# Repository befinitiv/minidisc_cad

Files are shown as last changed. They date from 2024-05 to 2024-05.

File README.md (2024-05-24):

# Minidisc

This repository contains the CAD files (PCB & mechanics) for the 8cm "minidisc" player project.

The PCB is designed using Kicad 8, the mechanics is designed using build123d.

## Buld123d environment installation

1. Install direnv
2. Go into the mech/ subfolder, so that the Python environment specified in .envrc file is loaded
3. Install packages: `pip install -r requirements.txt`
4. Start GUI: `jupyter lab`

# BOM
* Display: https://www.reichelt.de/grafik-oled-0-84-zoll-96x16-dot-weiss-ziff-ea-w096016-xblw-p364744.html?&nbc=1
* Bluray drive: https://www.reichelt.de/verbatim-externer-slimline-blu-ray-brenner-verbatim-43889-p264365.html?search=bluray
* Battery: https://www.reichelt.de/mp3-player-akku-fuer-apple-ipod-li-po-1043-mah-akku-30933-p224503.html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
* All other parts are within the Kicad PCB BOM

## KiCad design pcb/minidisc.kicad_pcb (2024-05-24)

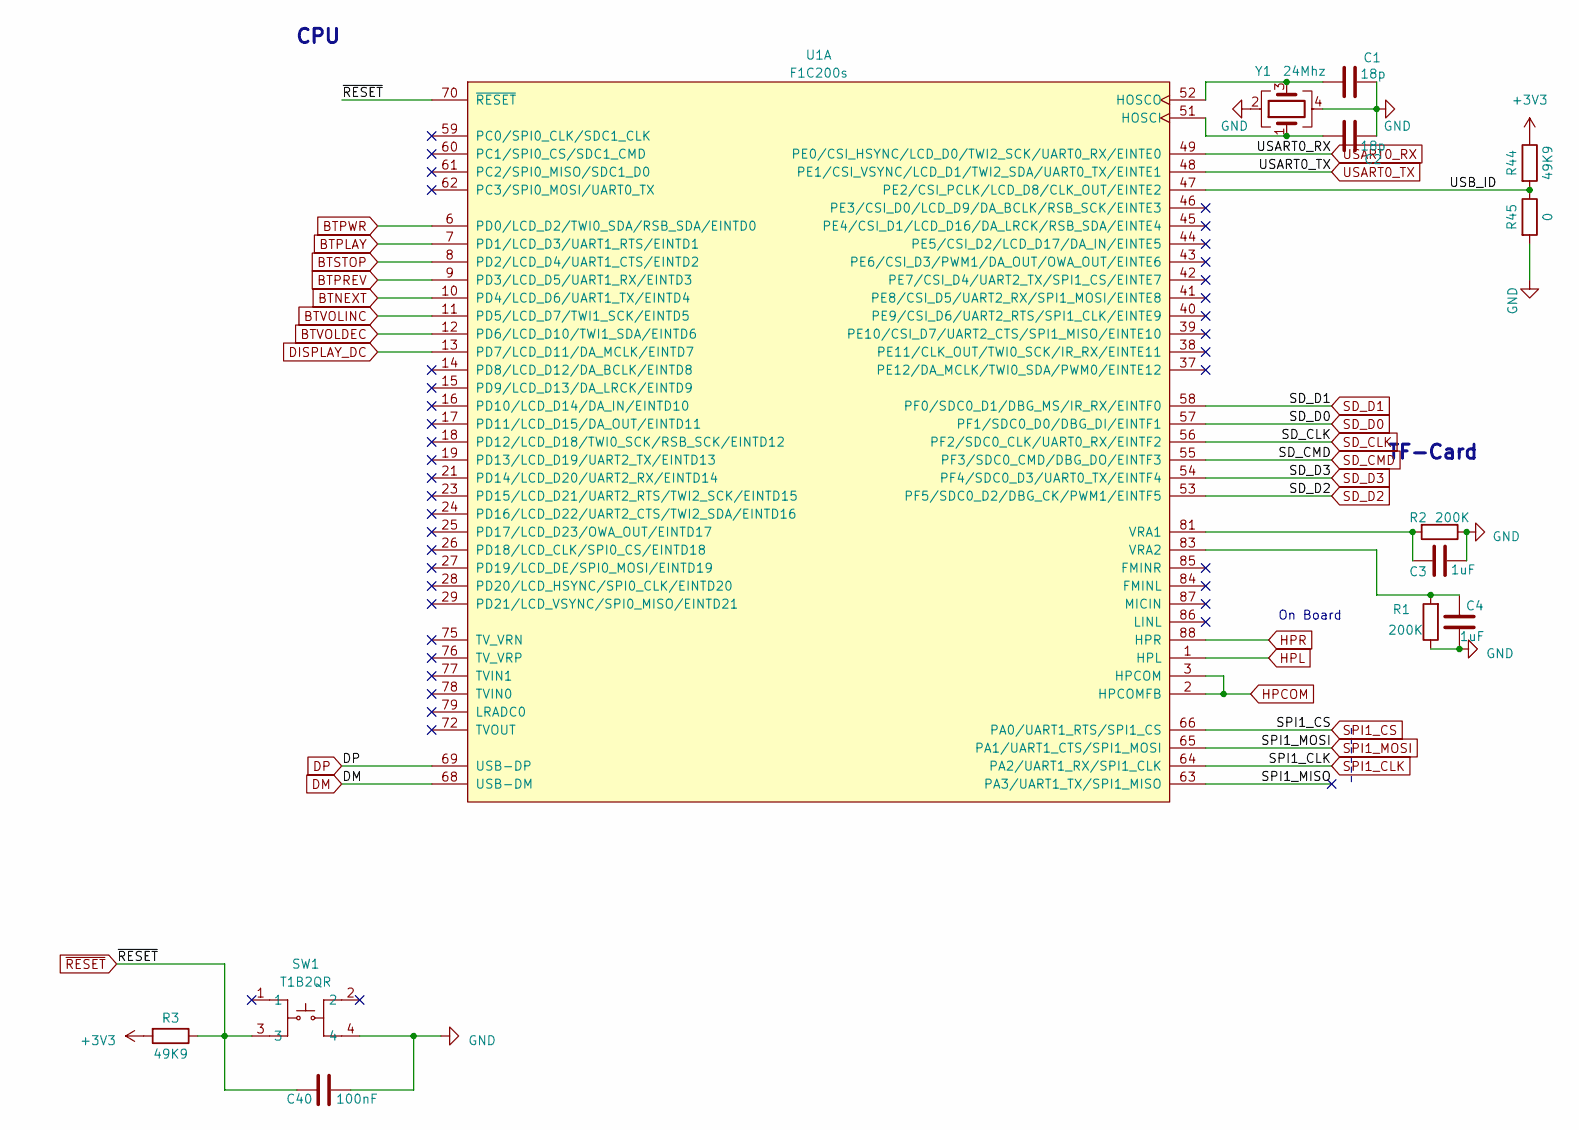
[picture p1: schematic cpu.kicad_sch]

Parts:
C1, C2: 18p; C_0402_1005Metric
C3, C4: 1uF; C_0402_1005Metric
C40: 100nF; C_0402_1005Metric_Pad0.74x0.62mm_HandSolder
R1, R2: 200K; R_0402_1005Metric_Pad0.72x0.64mm_HandSolder
R3, R44: 49K9; R_0402_1005Metric_Pad0.72x0.64mm_HandSolder
R45: 0; R_0402_1005Metric_Pad0.72x0.64mm_HandSolder
SW1: T1B2QR; KEY-SMD_4P-L2.6-W1.6-P0.80-LS3.0-1; LCSC Part C495946
U1: F1C200s; QFN-88_L10.0-W10.0-P0.40-BL-EP6.75
Y1: 24Mhz; Crystal_SMD_3225-4Pin_3.2x2.5mm; LCSC C5160135

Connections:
+3V3: R3.2, R44.1; also elsewhere on the board
/cpu/SPI1_MISO: U1.63 (PA3/UART1_TX/SPI1_MISO)
/cpu/USB_ID: R44.2, R45.1, U1.47 (PE2/CSI_PCLK/LCD_D8/CLK_OUT/EINTE2)
BTNEXT: U1.10 (PD4/LCD_D6/UART1_TX/EINTD4); also elsewhere on the board
BTPLAY: U1.7 (PD1/LCD_D3/UART1_RTS/EINTD1); also elsewhere on the board
BTPREV: U1.9 (PD3/LCD_D5/UART1_RX/EINTD3); also elsewhere on the board
BTPWR: U1.6 (PD0/LCD_D2/TWI0_SDA/RSB_SDA/EINTD0); also elsewhere on the board
BTSTOP: U1.8 (PD2/LCD_D4/UART1_CTS/EINTD2); also elsewhere on the board
BTVOLDEC: U1.12 (PD6/LCD_D10/TWI1_SDA/EINTD6); also elsewhere on the board
BTVOLINC: U1.11 (PD5/LCD_D7/TWI1_SCK/EINTD5); also elsewhere on the board
DISPLAY_DC: U1.13 (PD7/LCD_D11/DA_MCLK/EINTD7); also elsewhere on the board
DM: U1.68 (USB-DM); also elsewhere on the board
DP: U1.69 (USB-DP); also elsewhere on the board
GND: C1.1, C2.1, C3.1, C4.1, C40.2, R1.1, R2.1, R45.2, SW1.4, Y1.2, Y1.4; also elsewhere on the board
HPCOM: U1.2 (HPCOMFB), U1.3 (HPCOM); also elsewhere on the board
HPL: U1.1 (HPL); also elsewhere on the board
HPR: U1.88 (HPR); also elsewhere on the board
unnamed: C2.2, U1.51 (HOSCI), Y1.1
unnamed: C1.2, U1.52 (HOSCO), Y1.3
unnamed: C3.2, R2.2, U1.81 (VRA1)
unnamed: C4.2, R1.2, U1.83 (VRA2)
SD_D0: U1.57 (PF1/SDC0_D0/DBG_DI/EINTF1); also elsewhere on the board
SD_D1: U1.58 (PF0/SDC0_D1/DBG_MS/IR_RX/EINTF0); also elsewhere on the board
SD_D2: U1.53 (PF5/SDC0_D2/DBG_CK/PWM1/EINTF5); also elsewhere on the board
SD_D3: U1.54 (PF4/SDC0_D3/UART0_TX/EINTF4); also elsewhere on the board
SPI1_CLK: U1.64 (PA2/UART1_RX/SPI1_CLK); also elsewhere on the board
SPI1_CS: U1.66 (PA0/UART1_RTS/SPI1_CS); also elsewhere on the board
SPI1_MOSI: U1.65 (PA1/UART1_CTS/SPI1_MOSI); also elsewhere on the board
USART0_RX: U1.49 (PE0/CSI_HSYNC/LCD_D0/TWI2_SCK/UART0_RX/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); also elsewhere on the board
USART0_TX: U1.48 (PE1/CSI_VSYNC/LCD_D1/TWI2_SDA/UART0_TX/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); also elsewhere on the board
~RESET: C40.1, R3.1, SW1.3, U1.70 (~RESET); also elsewhere on the board

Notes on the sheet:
On Board
TF-Card
CPU

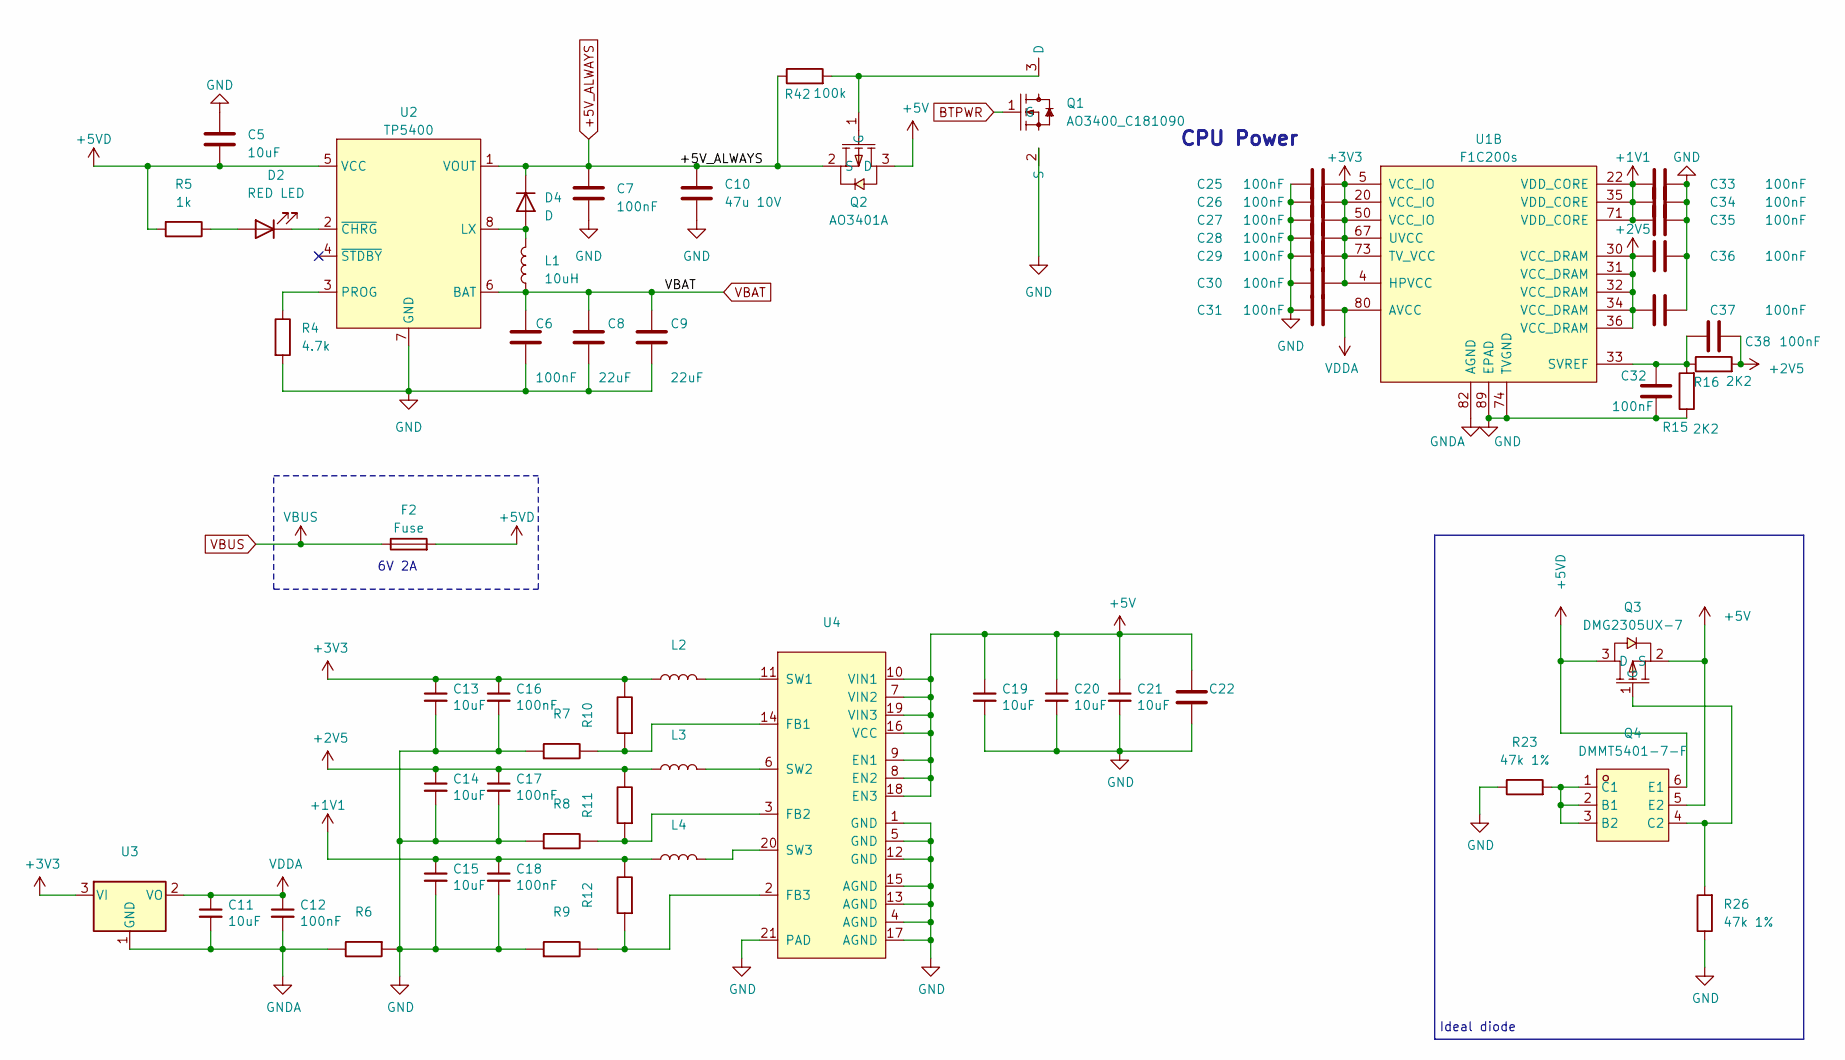
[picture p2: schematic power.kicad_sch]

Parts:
C5: 10uF; C_0603_1608Metric
C6: 100nF; C_0402_1005Metric
C7, C25, C26, C27, C28, C29, C30, C31, C32, C33, C34, C35, C36, C37, C38: 100nF; C_0402_1005Metric_Pad0.74x0.62mm_HandSolder
C8, C9: 22uF; C_0805_2012Metric
C10, C22: 47u 10V; C_1210_3225Metric
C11, C13, C14, C15, C19, C20, C21: 03.4004_C0603_10uF; C_0603_1608Metric
C12, C16, C17: 03.0009_C0402_100nF; C_0402_1005Metric
C18: 03.0009_C0402_100nF; R_0402_1005Metric
D2: RED LED; LED_0402_1005Metric
D4: D; D_SMA; LCSC C34897
F2: Fuse; Fuse_1206_3216Metric; LCSC C720076
L1: 10uH; IND-SMD_L4.0-W4.0
L2, L3, L4: 06.0102_L2520_2.2uH; L_1008_2520Metric; LCSC C315721
Q1: AO3400_C181090; SOT-23-3_L2.9-W1.3-P1.90-LS2.4-BR; LCSC Part C181090
Q2: AO3401A; SOT-23_L2.9-W1.3-P1.90-LS2.4-BR; LCSC Part C15127
Q3: DMG2305UX-7; SOT-23-3_L2.9-W1.3-P1.90-LS2.4-BR; LCSC Part C150470
Q4: DMMT5401-7-F; SOT-23-6_L2.9-W1.6-P0.95-LS2.8-BR; LCSC Part C154733
R4: 4.7k; R_0402_1005Metric
R5: 1k; R_0402_1005Metric
R6: 0; R_0402_1005Metric
R7, R8, R9, R12: 150K 1%; R_0402_1005Metric; LCSC C3015896
R10: 680K 1%; R_0402_1005Metric; LCSC C2909377
R11: 470K 1%; R_0402_1005Metric
R15, R16: 2K2; R_0402_1005Metric_Pad0.72x0.64mm_HandSolder
R23, R26: 47k 1%; R_0402_1005Metric
R42: 100k; R_0402_1005Metric_Pad0.72x0.64mm_HandSolder
U1: F1C200s; QFN-88_L10.0-W10.0-P0.40-BL-EP6.75
U2: TP5400; ESOP-8_L4.9-W3.9-P1.27-LS6.0-BL-EP
U3: 09.0103_XC6206; SOT-23; LCSC C347375
U4: 09.0102_EA3036; WQFN-20-1EP_3x3mm_P0.4mm_EP1.7x1.7mm_ThermalVias; LCSC C570857

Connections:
+1V1: C15.1, C18.1, C33.1, C34.1, C35.1, L4.1, R12.2, U1.22 (VDD_CORE), U1.35 (VDD_CORE), U1.71 (VDD_CORE)
+2V5: C14.1, C17.1, C36.1, C37.1, C38.1, L3.1, R11.2, R16.2, U1.30 (VCC_DRAM), U1.31 (VCC_DRAM), U1.32 (VCC_DRAM), U1.34 (VCC_DRAM), U1.36 (VCC_DRAM)
+3V3: C13.1, C16.1, C25.2, C26.2, C27.2, C28.2, C29.2, C30.2, L2.1, R10.2, U1.4 (HPVCC), U1.5 (VCC_IO), U1.20 (VCC_IO), U1.50 (VCC_IO), U1.67 (UVCC), U1.73 (TV_VCC), U3.3 (VI); also elsewhere on the board
+5V: C19.1, C20.1, C21.1, C22.1, Q2.3 (D), Q3.2 (S), Q4.5 (E2), U4.7 (VIN2), U4.8 (EN2), U4.9 (EN1), U4.10 (VIN1), U4.16 (VCC), U4.18 (EN3), U4.19 (VIN3); also elsewhere on the board
+5VD: C5.2, F2.2, Q3.3 (D), Q4.6 (E1), R5.2, U2.5 (VCC); also elsewhere on the board
+5V_ALWAYS: C7.1, C10.1, D4.1 (K), Q2.2 (S), R42.1, U2.1 (VOUT); also elsewhere on the board
BTPWR: Q1.1 (G); also elsewhere on the board
GND: C5.1, C6.2, C7.2, C8.2, C9.2, C10.2, C13.2, C14.2, C15.2, C16.2, C17.2, C18.2, C19.2, C20.2, C21.2, C22.2, C25.1, C26.1, C27.1, C28.1, C29.1, C30.1, C31.1, C32.1, C33.2, C34.2, C35.2, C36.2, C37.2, Q1.2 (S), R4.2, R6.1, R7.1, R8.1, R9.1, R15.1, R23.1, R26.1, U1.74 (TVGND), U1.89 (EPAD), U2.7 (GND), U4.1 (GND), U4.4 (AGND), U4.5 (GND), U4.12 (GND), U4.13 (AGND), U4.15 (AGND), U4.17 (AGND), U4.21 (PAD); also elsewhere on the board
GNDA: C11.2, C12.2, R6.2, U1.82 (AGND), U3.1 (GND)
unnamed: D2.2 (A), R5.1
unnamed: D2.1 (K), U2.2 (~CHRG)
unnamed: D4.2 (A), L1.1, U2.8 (LX)
unnamed: Q1.3 (D), Q2.1 (G), R42.2
unnamed: Q3.1 (G), Q4.4 (C2), R26.2
unnamed: Q4.1 (C1), Q4.2 (B1), Q4.3 (B2), R23.2
unnamed: C32.2, C38.2, R15.2, R16.1, U1.33 (SVREF)
unnamed: R4.1, U2.3 (PROG)
unnamed: R7.2, R10.1, U4.14 (FB1)
unnamed: R8.2, R11.1, U4.3 (FB2)
unnamed: R9.2, R12.1, U4.2 (FB3)
unnamed: L2.2, U4.11 (SW1)
unnamed: L3.2, U4.6 (SW2)
unnamed: L4.2, U4.20 (SW3)
VBAT: C6.1, C8.1, C9.1, L1.2, U2.6 (BAT); also elsewhere on the board
VBUS: F2.1; also elsewhere on the board
VDDA: C11.1, C12.1, C31.2, U1.80 (AVCC), U3.2 (VO)

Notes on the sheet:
6V 2A
CPU Power
Ideal diode

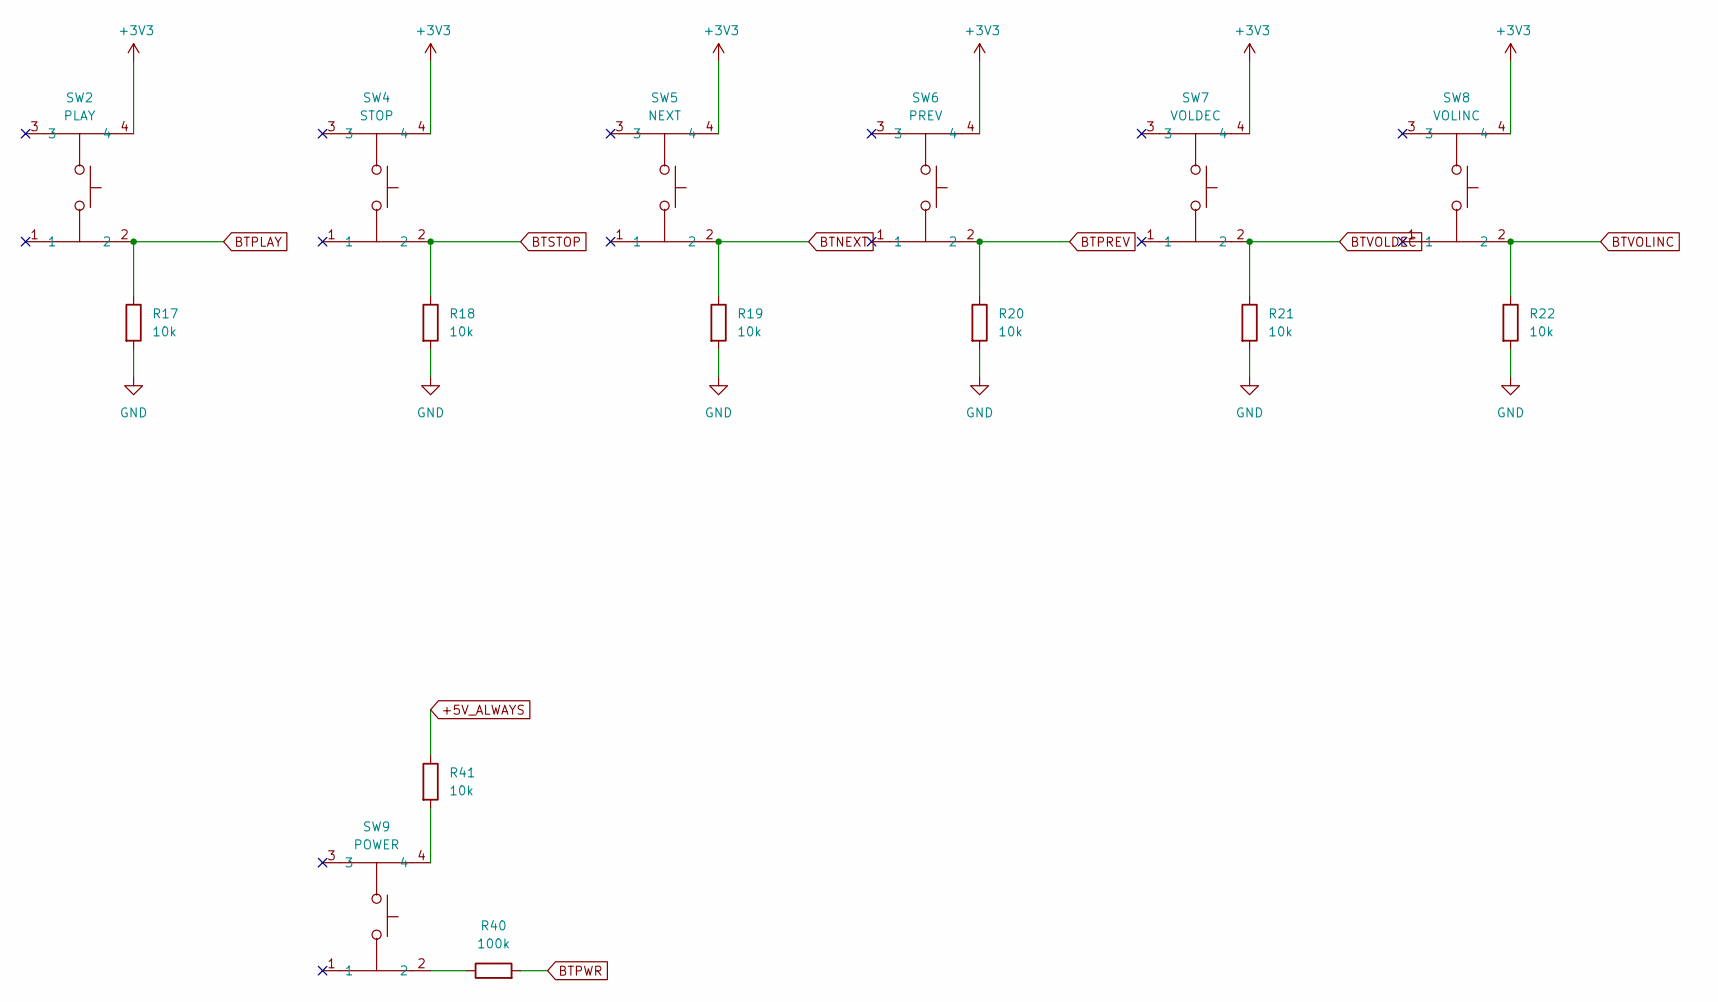
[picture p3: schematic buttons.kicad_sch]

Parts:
R17, R18, R19, R20, R21, R22, R41: 10k; R_0402_1005Metric
R40: 100k; R_0402_1005Metric
SW2: PLAY; SW-SMD_4P-L3.5-W2.9-P1.30-LS4.8; LCSC Part C130445
SW4: STOP; SW-SMD_4P-L3.5-W2.9-P1.30-LS4.8; LCSC Part C130445
SW5: NEXT; SW-SMD_4P-L3.5-W2.9-P1.30-LS4.8; LCSC Part C130445
SW6: PREV; SW-SMD_4P-L3.5-W2.9-P1.30-LS4.8; LCSC Part C130445
SW7: VOLDEC; SW-SMD_4P-L3.5-W2.9-P1.30-LS4.8; LCSC Part C130445
SW8: VOLINC; SW-SMD_4P-L3.5-W2.9-P1.30-LS4.8; LCSC Part C130445
SW9: POWER; SW-SMD_4P-L3.5-W2.9-P1.30-LS4.8; LCSC Part C130445

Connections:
+3V3: SW2.4, SW4.4, SW5.4, SW6.4, SW7.4, SW8.4; also elsewhere on the board
+5V_ALWAYS: R41.1; also elsewhere on the board
BTNEXT: R19.1, SW5.2; also elsewhere on the board
BTPLAY: R17.1, SW2.2; also elsewhere on the board
BTPREV: R20.1, SW6.2; also elsewhere on the board
BTPWR: R40.2; also elsewhere on the board
BTSTOP: R18.1, SW4.2; also elsewhere on the board
BTVOLDEC: R21.1, SW7.2; also elsewhere on the board
BTVOLINC: R22.1, SW8.2; also elsewhere on the board
GND: R17.2, R18.2, R19.2, R20.2, R21.2, R22.2; also elsewhere on the board
unnamed: R40.1, SW9.2
unnamed: R41.2, SW9.4

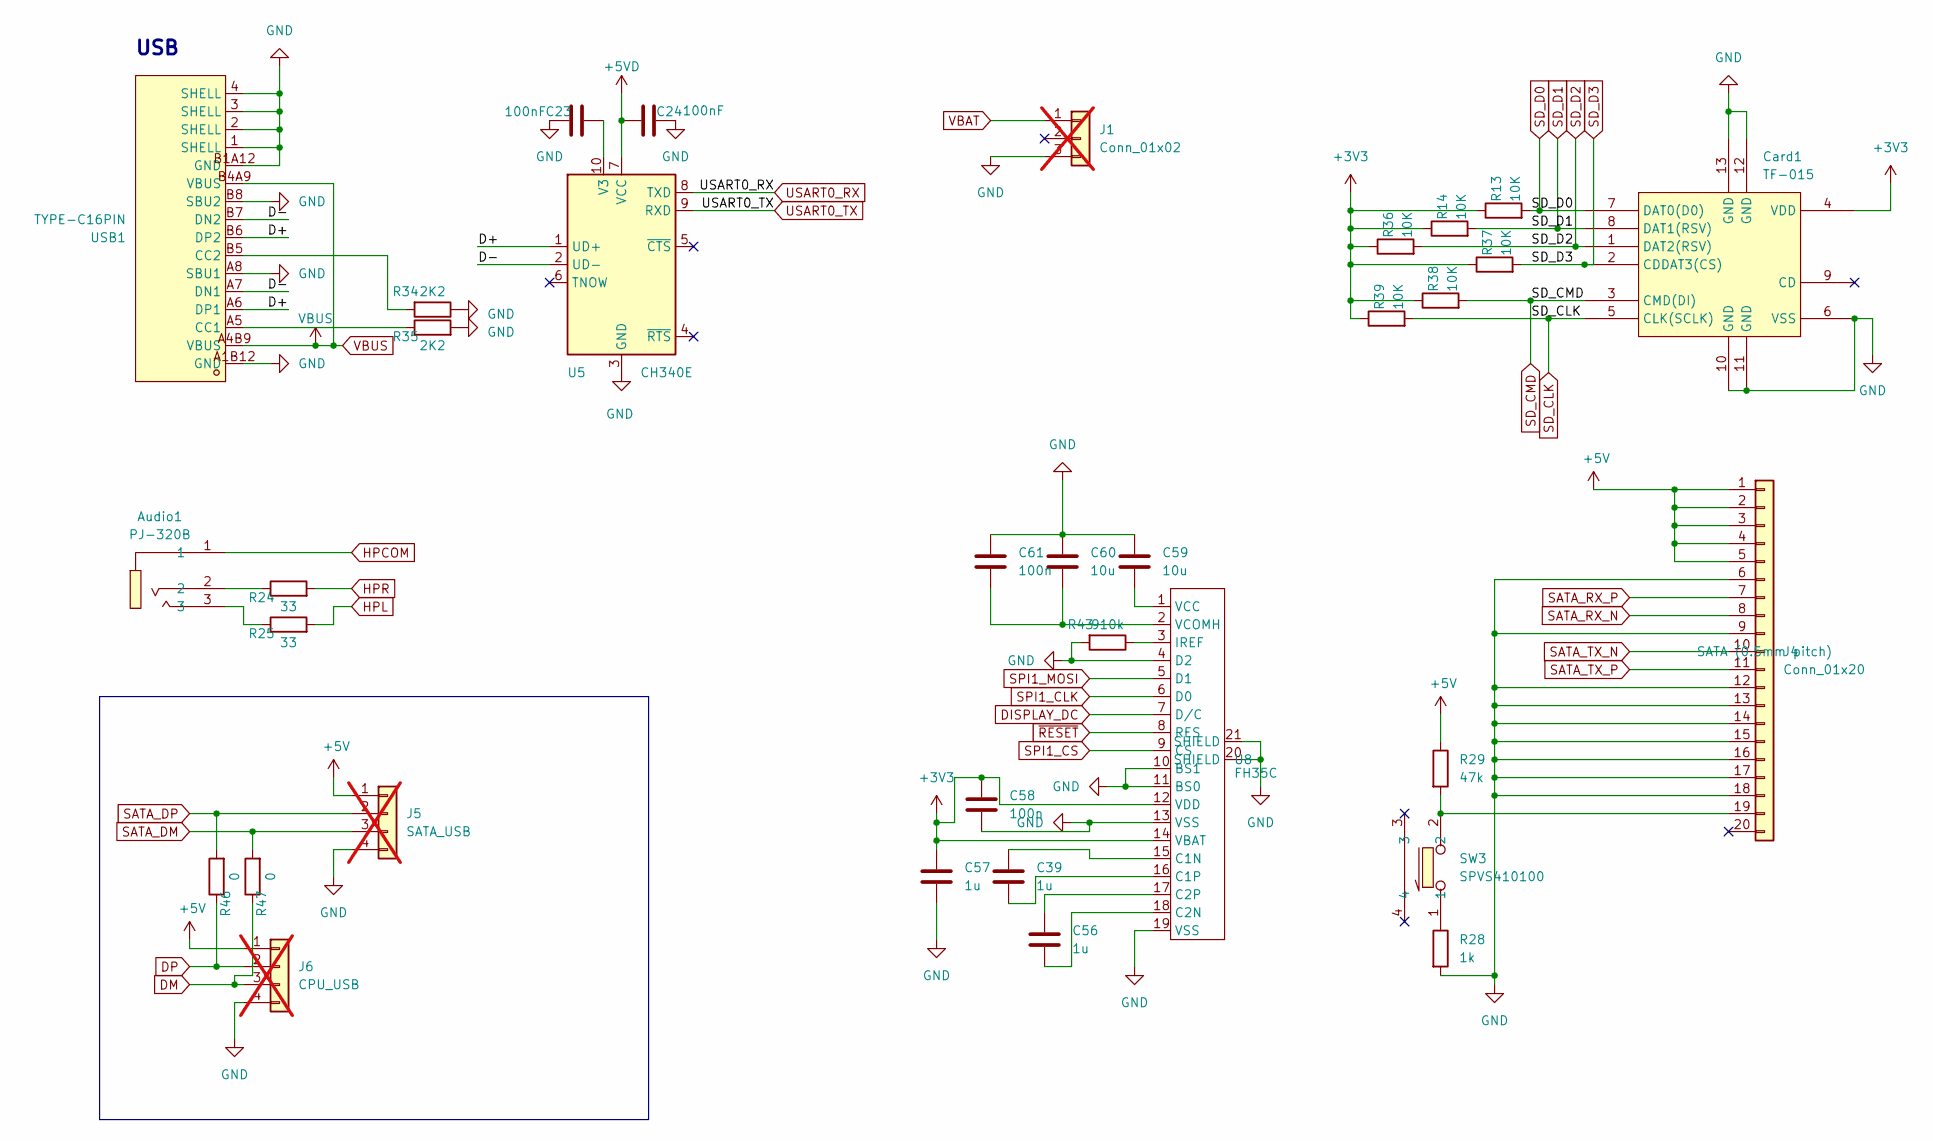
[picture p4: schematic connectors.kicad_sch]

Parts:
Audio1: PJ-320B; AUDIO-SMD_PJ-320B; LCSC Part C18594
C23, C24: 100nF; C_0402_1005Metric_Pad0.74x0.62mm_HandSolder
C39, C56, C57: 1u; C_0402_1005Metric
C58, C61: 100n; C_0402_1005Metric
C59, C60: 10u; C_0603_1608Metric
Card1: TF-015; TF-SMD_TF-015; LCSC Part C113206
J1: Conn_01x02; ipodbattery; not fitted
J4: Conn_01x20; Hirose_FH12-20S-0.5SH_1x20-1MP_P0.50mm_Horizontal; LCSC C596730
J5: SATA_USB; PinHeader_1x04_P1.00mm_Vertical; not fitted
J6: CPU_USB; PinHeader_1x04_P1.00mm_Vertical; not fitted
R13, R14, R36, R37, R38, R39: 10K; R_0402_1005Metric_Pad0.72x0.64mm_HandSolder
R24, R25: 33; R_0402_1005Metric_Pad0.72x0.64mm_HandSolder
R28: 1k; R_0402_1005Metric
R29: 47k; R_0402_1005Metric
R34, R35: 2K2; R_0402_1005Metric_Pad0.72x0.64mm_HandSolder
R43: 910k; R_0402_1005Metric_Pad0.72x0.64mm_HandSolder
R46, R47: 0; R_0402_1005Metric_Pad0.72x0.64mm_HandSolder
SW3: SPVS410100; SW-SMD_SPVS410100; LCSC Part C160857
U5: CH340E; MSOP-10_3x3mm_P0.5mm
U8: FH35C; FPC-SMD_19P-P0.60_HRS_FH35C-19S-0.3SHW
USB1: TYPE-C16PIN; USB-C-SMD_TYPE-C16PIN; LCSC Part C393939

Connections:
+3V3: C57.1, C58.1, Card1.4 (VDD), R13.1, R14.1, R36.1, R37.1, R38.1, R39.1, U8.12 (VDD), U8.14 (VBAT); also elsewhere on the board
+5V: J4.1, J4.2, J4.3, J4.4, J4.5, J5.1, J6.1, R29.1; also elsewhere on the board
+5VD: C24.1, U5.7 (VCC); also elsewhere on the board
/connectors/D+: U5.1 (UD+), USB1.A6 (DP1), USB1.B6 (DP2)
/connectors/D-: U5.2 (UD-), USB1.A7 (DN1), USB1.B7 (DN2)
DISPLAY_DC: U8.7 (D/C); also elsewhere on the board
DM: J6.3, R47.1; also elsewhere on the board
DP: J6.2, R46.1; also elsewhere on the board
GND: C23.2, C24.2, C57.2, C58.2, C59.1, C60.1, C61.1, Card1.6 (VSS), Card1.10 (GND), Card1.11 (GND), Card1.12 (GND), Card1.13 (GND), J1.3, J4.6, J4.9, J4.12, J4.13, J4.14, J4.15, J4.16, J4.17, J4.18, J5.4, J6.4, R28.2, R34.1, R35.2, R43.2, U5.3 (GND), U8.4 (D2), U8.10 (BS1), U8.11 (BS0), U8.13 (VSS), U8.19 (VSS), U8.20 (SHIELD), U8.21 (SHIELD), USB1.1 (SHELL), USB1.2 (SHELL), USB1.3 (SHELL), USB1.4 (SHELL), USB1.A1B12 (GND), USB1.A8 (SBU1), USB1.B1A12 (GND), USB1.B8 (SBU2); also elsewhere on the board
HPCOM: Audio1.1; also elsewhere on the board
HPL: R25.2; also elsewhere on the board
HPR: R24.2; also elsewhere on the board
unnamed: Audio1.2, R24.1
unnamed: Audio1.3, R25.1
unnamed: J4.19, R29.2, SW3.2
unnamed: R28.1, SW3.1
unnamed: C23.1, U5.10 (V3)
unnamed: C39.1, U8.15 (C1N)
unnamed: C39.2, U8.16 (C1P)
unnamed: C56.2, U8.18 (C2N)
unnamed: C56.1, U8.17 (C2P)
unnamed: R43.1, U8.3 (IREF)
unnamed: C59.2, U8.1 (VCC)
unnamed: C60.2, C61.2, U8.2 (VCOMH)
unnamed: R35.1, USB1.A5 (CC1)
unnamed: R34.2, USB1.B5 (CC2)
SATA_DM: J5.3, R47.2; also elsewhere on the board
SATA_DP: J5.2, R46.2; also elsewhere on the board
SATA_RX_N: J4.8; also elsewhere on the board
SATA_RX_P: J4.7; also elsewhere on the board
SATA_TX_N: J4.10; also elsewhere on the board
SATA_TX_P: J4.11; also elsewhere on the board
SD_D0: Card1.7 (DAT0(D0)), R13.2; also elsewhere on the board
SD_D1: Card1.8 (DAT1(RSV)), R14.2; also elsewhere on the board
SD_D2: Card1.1 (DAT2(RSV)), R36.2; also elsewhere on the board
SD_D3: Card1.2 (CDDAT3(CS)), R37.2; also elsewhere on the board
SPI1_CLK: U8.6 (D0); also elsewhere on the board
SPI1_CS: U8.9 (CS); also elsewhere on the board
SPI1_MOSI: U8.5 (D1); also elsewhere on the board
USART0_RX: U5.8 (TXD); also elsewhere on the board
USART0_TX: U5.9 (RXD); also elsewhere on the board
VBAT: J1.1; also elsewhere on the board
VBUS: USB1.A4B9 (VBUS), USB1.B4A9 (VBUS); also elsewhere on the board
~RESET: U8.8 (RES); also elsewhere on the board

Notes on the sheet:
USB

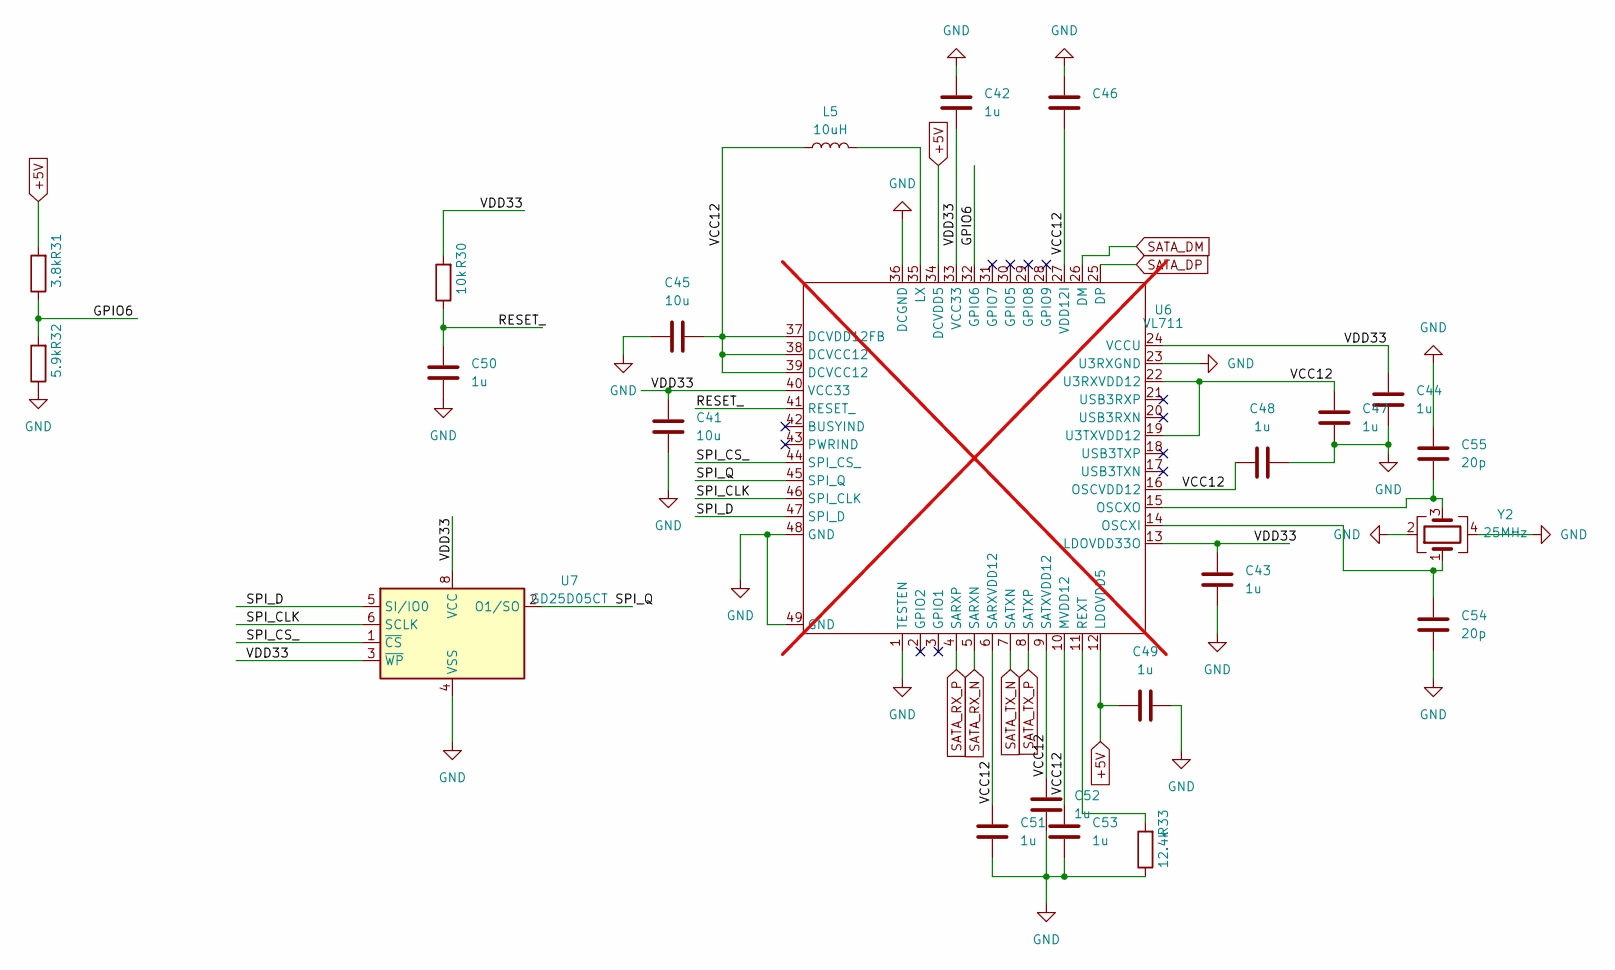
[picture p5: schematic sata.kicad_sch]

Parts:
C41, C45: 10u; C_0603_1608Metric
C42, C43, C44, C46, C47, C48, C49, C50, C51, C52, C53: 1u; C_0402_1005Metric
C54, C55: 20p; C_0402_1005Metric
L5: 10uH; L_1206_3216Metric
R30: 10k; R_0402_1005Metric_Pad0.72x0.64mm_HandSolder
R31: 3.8k; R_0402_1005Metric_Pad0.72x0.64mm_HandSolder; LCSC C102983
R32: 5.9k; R_0402_1005Metric_Pad0.72x0.64mm_HandSolder
R33: 12.4k; R_0402_1005Metric_Pad0.72x0.64mm_HandSolder
U6: VL711; QFN-48-1EP_6x6mm_P0.4mm_EP4.2x4.2mm_ThermalVias; not fitted
U7: GD25D05CT; SOP-8_3.9x4.9mm_P1.27mm
Y2: 25MHz; Crystal_SMD_3225-4Pin_3.2x2.5mm

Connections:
+5V: C49.1, R31.2, U6.12 (LDOVDD5), U6.34 (DCVDD5); also elsewhere on the board
/sata/GPIO6: R31.1, R32.2, U6.32 (GPIO6)
/sata/RESET_: C50.2, R30.1, U6.41 (RESET_)
/sata/SPI_CLK: U6.46 (SPI_CLK), U7.6 (SCLK)
/sata/SPI_CS_: U6.44 (SPI_CS_), U7.1 (~CS)
/sata/SPI_D: U6.47 (SPI_D), U7.5 (SI/IO0)
/sata/SPI_Q: U6.45 (SPI_Q), U7.2 (O1/SO)
/sata/VCC12: C45.2, C46.2, C47.1, C48.1, C51.2, C52.2, C53.2, L5.1, U6.6 (SARXVDD12), U6.9 (SATXVDD12), U6.10 (MVDD12), U6.16 (OSCVDD12), U6.19 (U3TXVDD12), U6.22 (U3RXVDD12), U6.27 (VDD12I), U6.37 (DCVDD12FB), U6.38 (DCVCC12), U6.39 (DCVCC12)
/sata/VDD33: C41.1, C42.2, C43.1, C44.1, R30.2, U6.13 (LDOVDD33O), U6.24 (VCCU), U6.33 (VCC33), U6.40 (VCC33), U7.3 (~WP), U7.8 (VCC)
GND: C41.2, C42.1, C43.2, C44.2, C45.1, C46.1, C47.2, C48.2, C49.2, C50.1, C51.1, C52.1, C53.1, C54.2, C55.1, R32.1, R33.1, U6.1 (TESTEN), U6.23 (U3RXGND), U6.36 (DCGND), U6.48 (GND), U6.49 (GND), U7.4 (VSS), Y2.2, Y2.4; also elsewhere on the board
unnamed: L5.2, U6.35 (LX)
unnamed: C54.1, U6.14 (OSCXI), Y2.1
unnamed: C55.2, U6.15 (OSCXO), Y2.3
unnamed: R33.2, U6.11 (REXT)
SATA_DM: U6.26 (DM); also elsewhere on the board
SATA_DP: U6.25 (DP); also elsewhere on the board
SATA_RX_N: U6.5 (SARXN); also elsewhere on the board
SATA_RX_P: U6.4 (SARXP); also elsewhere on the board
SATA_TX_N: U6.7 (SATXN); also elsewhere on the board
SATA_TX_P: U6.8 (SATXP); also elsewhere on the board

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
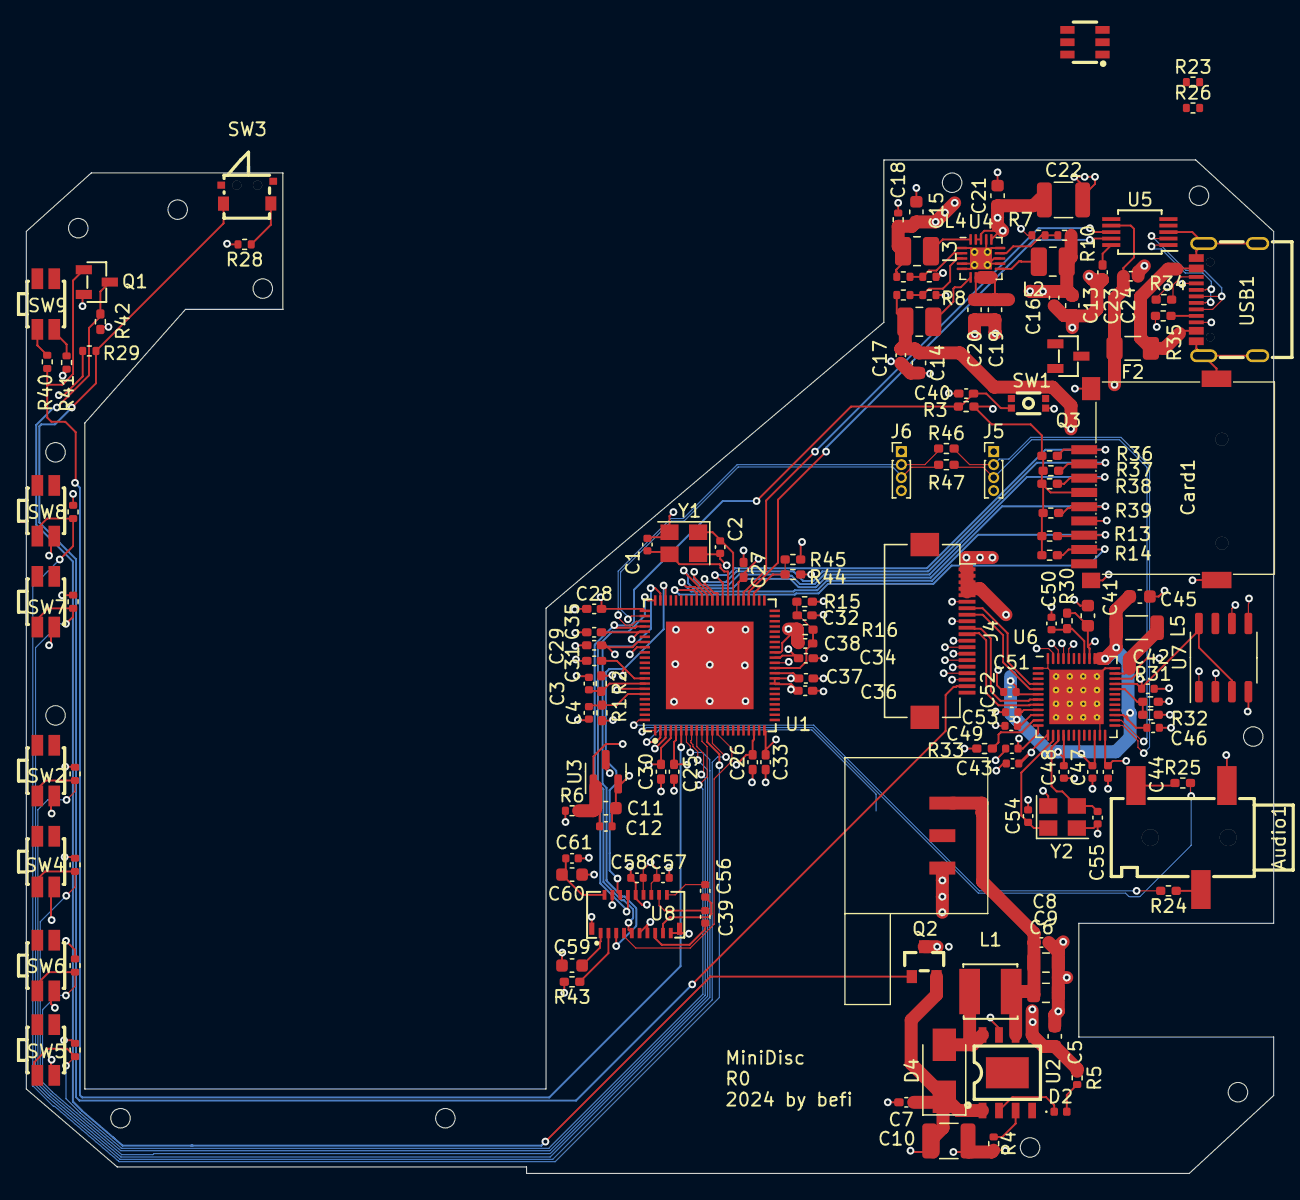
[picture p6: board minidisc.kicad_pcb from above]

Board: 4 copper layers, 96.0 x 78.0 mm, 145 parts (0 on the bottom side), 91 nets.

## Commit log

2024-04-18 Automated import of PCB screw holes, added holes for switches, usb-C, microsd & audio
2024-04-22 Added display cutout and buttons
2024-05-24 Added last minor patches like ideal diode on PCB, added backplate
    [buttons.kicad_sch, connectors.kicad_sch, cpu.kicad_sch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]
2024-05-24 Added BOM to readme
